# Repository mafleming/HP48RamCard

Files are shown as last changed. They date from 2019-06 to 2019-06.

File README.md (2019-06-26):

HP48RamCard Repository

# A 128K RAM Card for the HP48SX/HP48GX Calculator

This repository contains the schematics and Gerber files needed to create
a 128K RAM card for the HP-48SX/GX calculators. Data sheets for the parts
used are also included. The Bill of Material calls out specific vendor and
vendor part numbers for the passive components used, but any equivalent
part in the SMD 0805 package can be substituted.

The PCB board dimension is 2.125" wide by 3.375" high. The board thickness
is 0.8 mm (1/32") and a 0.8 mm plastic strip must be added so that the card
makes a snug fit in the calculator connector. A PCB thickness of 1.6 mm
can be used instead if a direct fit is desired, but many PCB houses treat
this as a special order size and charge accordingly. If you take this route
be sure to notch both sides of the PCB at the connector end for a distance
of about 1" and depth 0.1" in order to clear the latch engagement pin.

Battery backup is by use of a 12 mm lithium coin cell, either the CR1216 or
the CR1225. The CR1225 has the higher capacity rating of the two at 48 mAh.
Although that's only half the capacity of a CR2016, the Cypress MoBL SRAM
memory device only requires 1 uA in standby mode when the memory is not
selected so battery life should be reasonably long.

## Repository Content

The **Board** directory contains the schematic and PCB board images. Gerber
files are in the Gerber subdirectory. The **Datasheets** directory contains
relevant device information, copyright the manufacturer of course.

## Assembly Notes

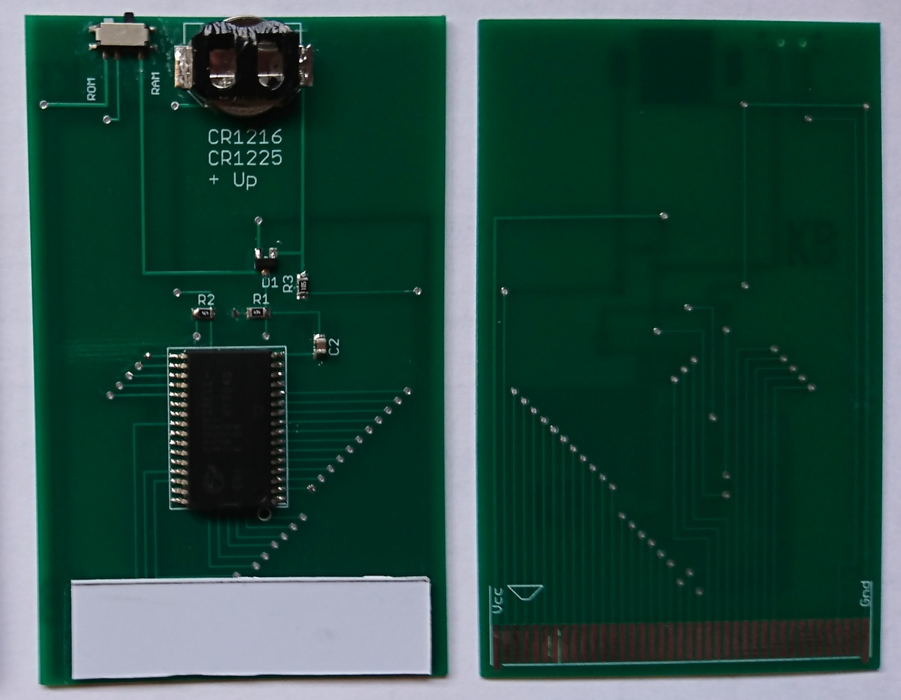
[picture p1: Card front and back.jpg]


The flexible contacts punched from the top of the battery holder are bent
downwards far enough to touch the PCB. Left as-is they will make it more
difficult to insert and remove the battery. The spring force can even be
enough to cause the solder bond between holder tab and PCB to fail
resulting in the battery popping out of the holder. Press the two spring
tabs upwards so that they are closer to the top of the holder.

The battery holder is held by solder to the PCB. Be sure to apply enough to
cover the contacts well because the holder will likely be subject to a
pulling force by those who grasp it to remove the card from the calculator.

The memory protect switch is a more suitable point to grasp the card when
removing it from the calculator. The switch is anchored at its four corners
by solder tabs. In addition, two pegs extend from the bottom of the switch
body into holes in the PCB. Pull upwards in the plane of the PCB.

The top of the battery holder is at the potential of the positive side of
the battery. The holder top presents a possibility of a short, so it is
advised to cover it with a strong adhesive tape or contact sheet. Better
yet, remove the chrome coating from the top with rough sandpaper prior to
soldering the holder to the board, then coat with paint or nail polish
after the soldering operation.

To insure the card contacts are pressed firmly against the card connector
contacts in a calculator, attach a strip of 0.8mm (1/32") thick plastic
behind the contacts on the component side of the PCB. The strip should
meet the lower edge of the PCB and extend upwards about 1/2", but should
not extend the full width of the PCB. Keep the strip about 1/4" from the
left and right sides so that it doesn't cause the card to be blocked by
guide tabs in the card connector block inside the calculator.

## Usage

The card may require a bit of wiggling to clear guide tabs molded into the
card connector assembly. These tabs help guide a commercial card and open
a spring-loaded cover protecting the card contacts. Insertion and removal
is fairly easy in either card slot of an HP48SX. It may help to turn the
calculator on its face and then some downward pressure applied to the back
of the card as the card is pressed down on the top edge.

Insertion in slot 1 of an HP48GX is slightly "stickier" but is easily done
by turning the calculator over. Slot 2 is a different story as the bottom
edge of the PCB catches on a ledge above the connector slot. A plastic
ruler can be use to press the back of the card near the bottom until it
clears the ledge. An alternative is to move the plastic strip from the front
to the back of the PCB just above the row of contacts. The downside is that
the card will now no longer fit in slot 1.

## Project Status

A set of boards were built and tested in HP48SX calculators and outside of
a calculator shell. All cards showed an initial decline in battery cell
voltage before stabilizing around 3 Volts. All cards maintained their
content across the multi-week test period.

The pullup resistor R1 on the Output Enable input to memory was found to be
unnecessary, but did not affect battery life during the test period. I
recommend not installing R1 on any board build.

Improvements to the design include using a smaller contact pad for the battery
bottom since the current size presents a slight risk of a short between the
bottom pad and battery housing if a metal probe is inserted in the general
area. Some designs show a 2.2K current limiting resistor in series with the
CdDet input. A resistor could be added to the design and a zero Ohm short
could be used if the resistor proves to be unnecessary.

The supply voltage to the switch when in the RAM position could be VccOn
from the calculator rather than the memory device supply Vcc. No detrimental
effect has been seen with the arrangement, but if battery life is
compromised as a result, the switch should be moved to the ROM position when
the card is not in use.

## Bill of Material

| Symbol | Device | Part Number | Notes |
| --- | --- | --- | --- |
| IC1 | Cypress 128Kx8 SRAM| CY62128ELL45SXI | SOIC28 |
| D1 | Dual Schottky Diode | ON Semi BAT54CLT1G | SOT23 |
| R2 | 470K, 5% | Panasonic ERJ-P06J474V | 0805 SMD |
| R3 | 1M, 5% | Yageo RC0805JR-071ML | 0805 SMD |
| C1 | 470nF, 16VDC | Taiyo Yuden EMK212B7474MG-T | 0805 SMD |
| U1 | Battery Hldr | Linx BAT-HLD-012-SMT | Use CR1216 or CR1225 |
| U2 | SPDT Switch | Apem MA12R | |

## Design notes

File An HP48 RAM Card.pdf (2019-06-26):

# An HP-48SX/GX 128K RAM Card

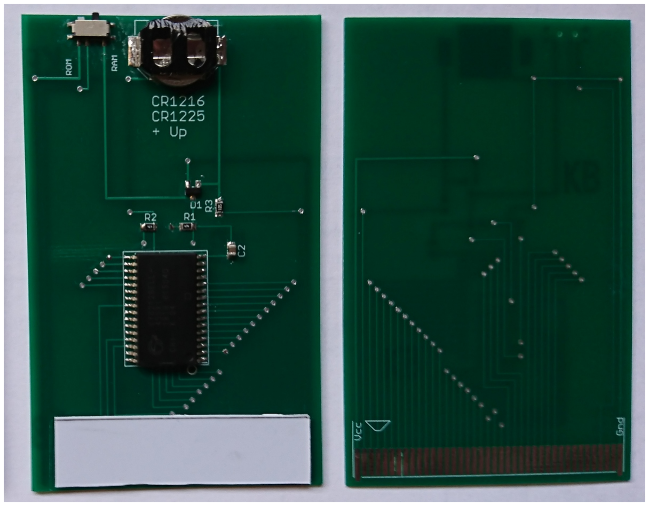
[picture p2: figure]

This repository contains the schematics and Gerber files needed to create a 128K RAM card for the HP-48SX/GX calculators. Data sheets for the parts used are also included. The Bill of Material calls out specific vendor and vendor part numbers for the passive components used, but any equivalent part in the SMD 0805 package can be substituted.
The PCB board dimension is 2.125" wide by 3.375" high. The board thickness is 0.8 mm (1/32") and a 0.8 mm plastic strip must be added so that the card makes a snug fit in the calculator connector. A PCB thickness of 1.6 mm can be used instead if a direct fit is desired, but many PCB houses treat this as a special order size and charge accordingly. If you take this route be sure to notch both sides of the PCB at the connector end for a distance of about 1" and depth 0.1" in order to clear the latch engagement pin.

Battery backup is by use of a 12 mm lithium coin cell, either the CR1216 or the CR1225. The CR1225 has the higher capacity rating of the two at 48 mAh. Although that's only half the capacity of a CR2016, the Cypress MoBL SRAM memory device only requires 1 uA in standby mode when the memory is not selected so battery life should be reasonably long.

### Assembly

Before soldering components thoroughly clean both sides of the PCB with isopropyl alcohol to remove any contaminants that may interfere with the soldering process. Be sure to have on hand plenty of flux to insure good solder wetting and flow.
I generally begin with the small SMD parts. Don’t solder R1 in place as it is not needed. The remaining components R2, R3, C1, and D1 can be held in place with tweezers while soldering. Pick up a bit of solder on your iron tip and bring the tip straight into the end of the component near board level and note the flow of solder under and around the component end. Add plenty of flux beforehand. Spin the board around and solder the other end of the component while applying downward pressure with the tweezers. When all SMD components are soldered you can touch up each solder joint by applying heat and a little more solder from top and sides of the joint.
Solder the memory IC next. The circle mark identifying pin 1 should be downward towards the connector edge of the card. Holding the IC in place, apply plenty of flux and then solder tack the pins at each end of the IC side nearest you. This will hold the IC in place as you solder the pins on the other side of the IC. Turn the card 180, apply flux and then solder each pin on the opposite side. Turn 180 again and solder each pin on the remaining side after applying more flux. If any flux evaporates while you are soldering, stop and apply more to keep your work wet as you go.
Visually inspect each pin for good solder coverage and insure there is no solder bridge between pins. I like to “ring out” the connections afterwards with a multimeter set to the continuity test position. To check for shorts, walk your meter probe pins across successive pairs of via holes surrounding the IC. You can check further by placing one probe on top of an IC pin and the other on its corresponding via. This check doesn’t take long and can save you quite a bit of headscratching if the card fails or acts strangely when you plug it in.
Solder the four corner pads of switch first, holding it in place with tweezers. The switch will align itself to the PCB with two pins on the bottom registering into two holes in the PCB. Be sure to have plenty of solder (and flux) on these corners as the switch will experience a fair amount of force when it is toggled from one position to the other. It is also the place to grab and pull when removing the card from a calculator. Finish with the three switch contact pins themselves and ring out the connections.
The flexible contacts punched from the top of the battery holder are bent downwards far enough to touch the PCB. Left as-is they will make it more difficult to insert and remove the battery. The spring force can even be enough to cause the solder bond between holder tab and PCB to fail resulting in the battery popping out of the holder. Press the two spring tabs upwards so that they are closer to the top of the holder.

The top of the battery holder is at the potential of the positive side of the battery. The holder top presents a possibility of a short, so I would advise covering it with a strong adhesive tape or contact sheet. Better yet, remove the chrome coating from the top with rough sandpaper prior to soldering the holder to the board, then coat with paint or nail polish after the soldering operation.
The battery holder is held by solder to the PCB. Be sure to apply enough to cover the contacts well because the holder will likely be subject to a pulling force by those who grasp it to remove the card from the calculator.
To insure the card contacts are pressed firmly against the card connector contacts in a calculator, attach a strip of 0.8mm (1/32") thick plastic behind the contacts on the component side of the PCB (photo above). The strip should meet the lower edge of the PCB and extend upwards about 1/2", but should not extend the full width of the PCB. Keep the strip about 1/4" from the left and right sides so that it doesn't cause the card to be blocked by guide tabs in the card connector block inside the calculator. Doublesided tape works well to hold the strip.

### Usage

The card may require a bit of wiggling to clear guide tabs molded into the card connector assembly. These tabs help guide a commercial card and open a spring-loaded cover protecting the card contacts. Insertion and removal is fairly easy in either card slot of an HP48SX. It may help to turn the calculator on its face and then apply some downward pressure to the back of the card as the card is pressed down on the top edge.
Insertion in slot 1 of an HP48GX is slightly "stickier" but is easily done by turning the calculator over. Slot 2 is a different story as the bottom edge of the PCB catches on a ledge above the connector slot. A plastic ruler can be use to press the back of the card near the bottom until it clears the ledge. An alternative is to move the plastic strip from the front to the back of the PCB just above the row of contacts. The downside is that now the card will no longer fit in slot 1.
When inserting the card for the first time the calculator will display an Invalid Card Data warning message. For an HP-48GX use the PINIT command to initialize the RAM. Be sure the memory protect switch is in the “RAM” position. For an HP-48SX a card in initialized by storing a variable to the card and then purging it. The calculator will take several seconds to perform the purge as it initializes the card. You can periodically check the voltage of the battery by touching multimeter probes to the top of the battery and a via located below and to the left of the battery holder near the RAM label.

### Bill of Materials

The passive components listed here can readily be substituted from another vendor as long as the value and voltage rating is preserved. The dual diode is also multi-sourced from other vendors. The parts are all available from Mouser as of this date (2019).
Symbol | Device | Part # | Notes
IC1 | Cypress 128Kx8 SRAM | CY62128ELL45SXI | SOIC-28
D1 | Dual Schottky Diode | ON Semi BAT54CLT1G | SOT23
R2 | 470K, 5% Resistor | Panasonic ERJ-P06J474V | SMD 0805
R3 | 1M, 5% Resistor | Yageo RC0805JR-071ML | SMD 0805
C1 | 470nF, 16VDC Capacitor | Taiyo Yuden EMK212B7474MG-T | SMD 0805
U1 | Battery Holder | Linx BAT-HLD-012-SMT | Use CR1216 or CR1225
U2 | SPDT Switch | Apem MA12R

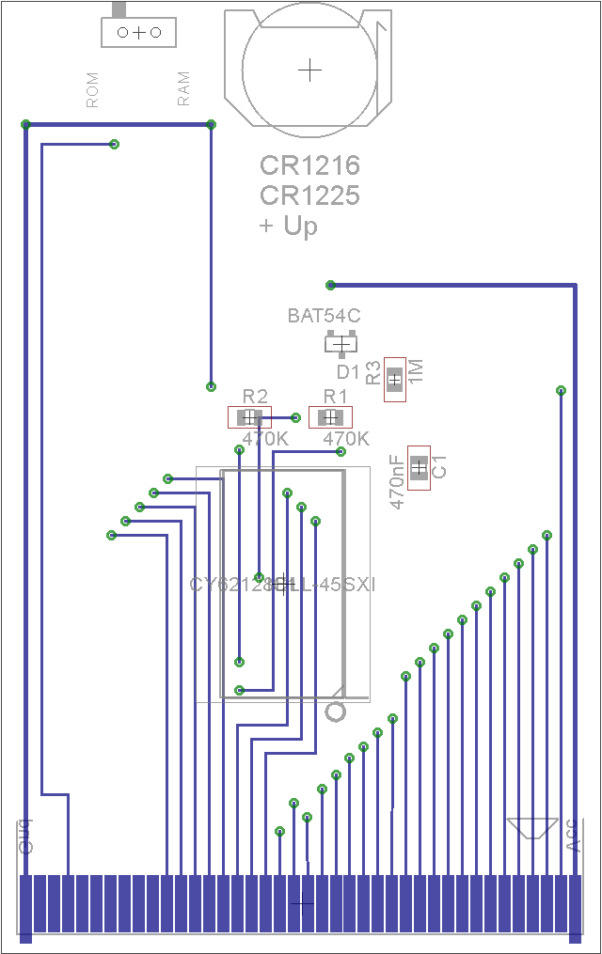
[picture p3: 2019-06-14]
Board/PCB Bottom.png

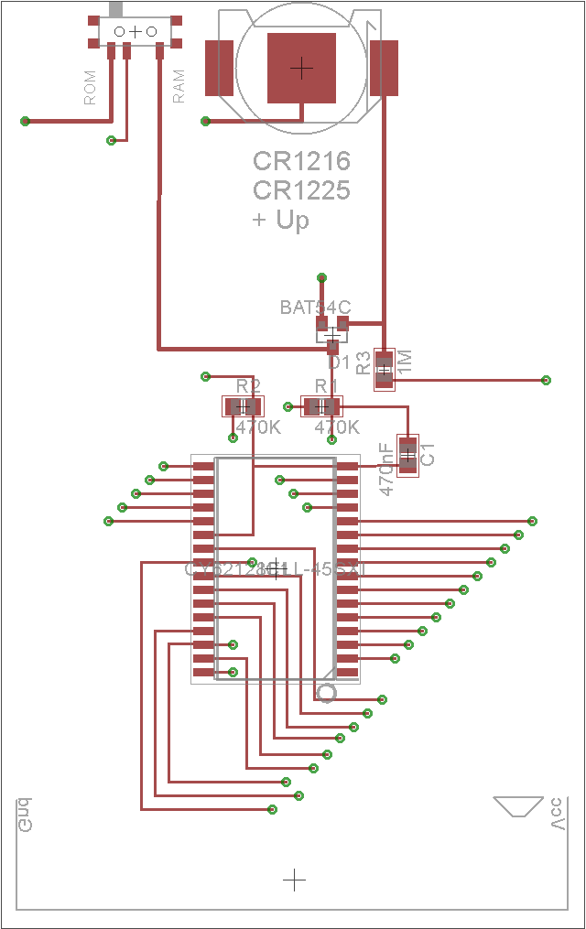
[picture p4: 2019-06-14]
Board/PCB Top.png

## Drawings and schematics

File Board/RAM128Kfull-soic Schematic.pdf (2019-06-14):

A

A

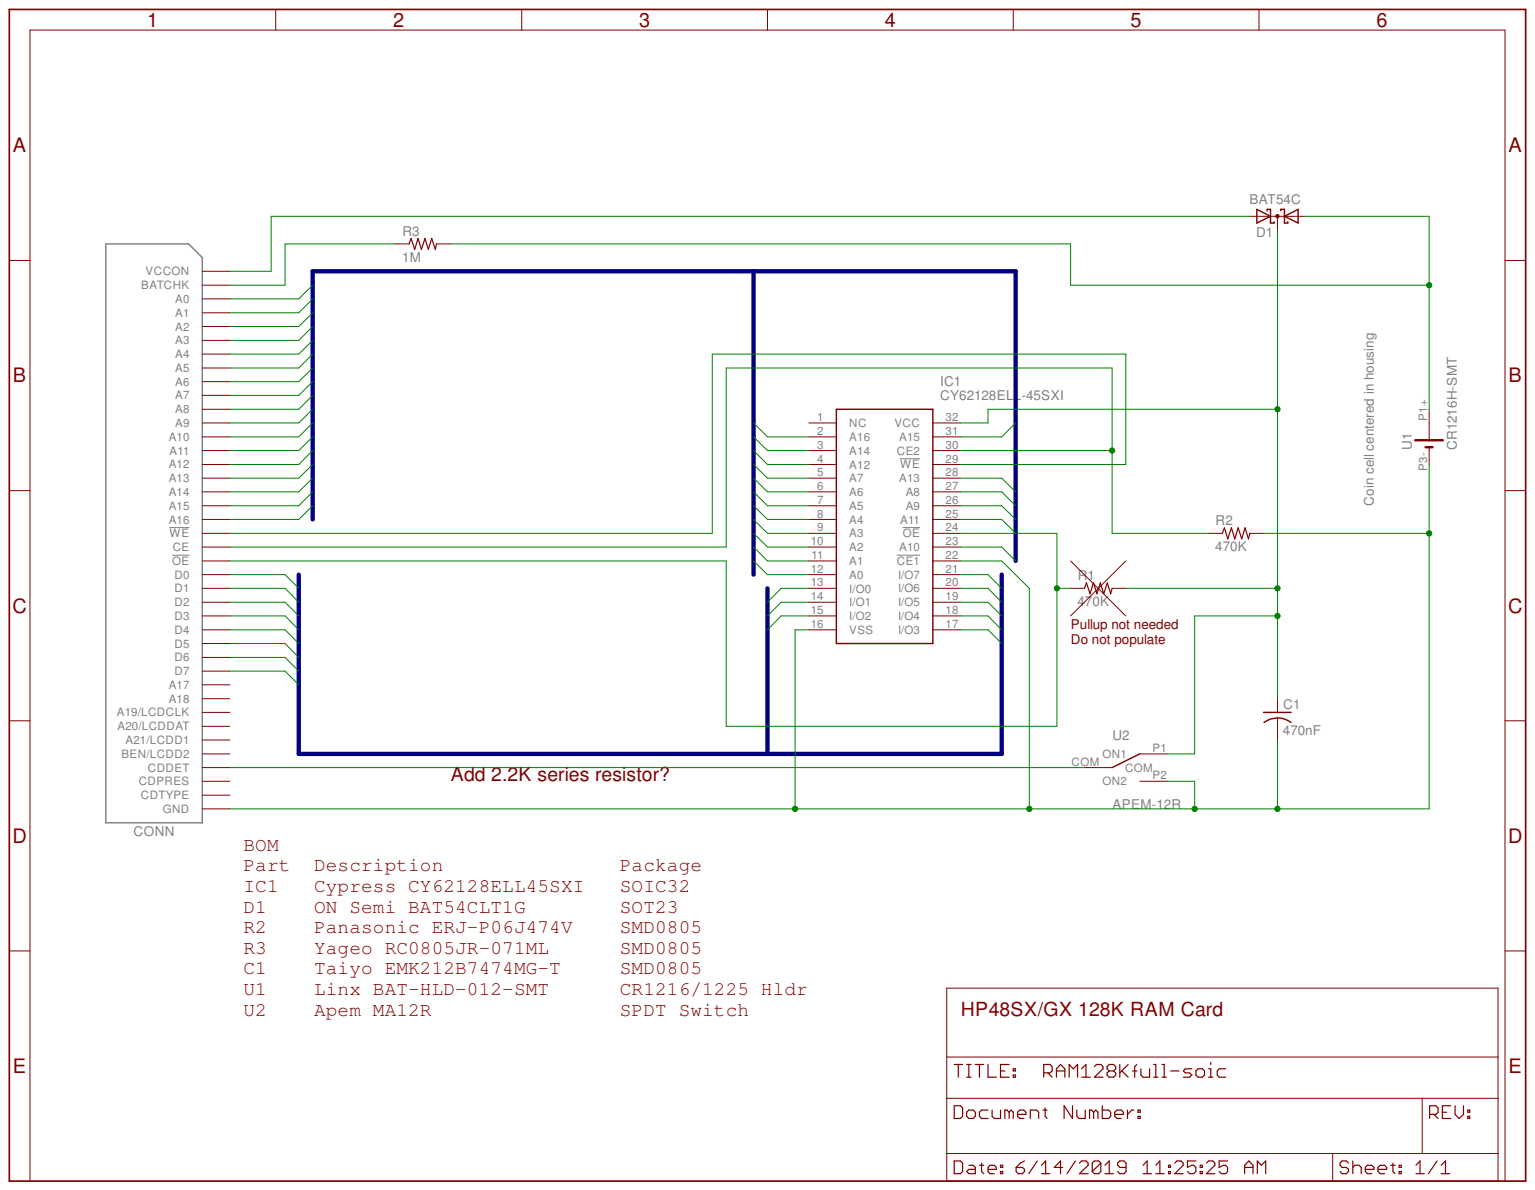
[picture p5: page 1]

Coin cell centered in housing

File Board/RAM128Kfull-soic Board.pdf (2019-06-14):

CR1216
CR1225

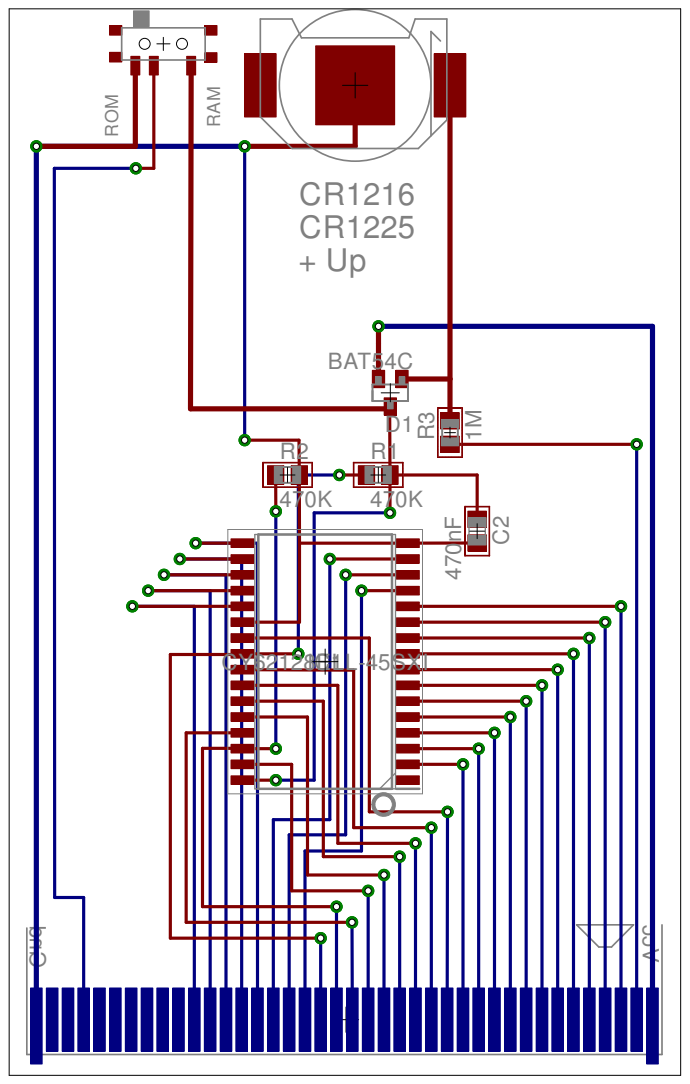
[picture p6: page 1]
Gnd; Vcc; ROM; RAM; BAT54C; CY62128ELL-45SXI

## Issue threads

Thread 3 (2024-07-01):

Make original design files available?

markaudacity, 2024-07-01:
This project has the information to produce a card, but not to improve the design with, EG, a 3D-printed shim with a label and pull tab, a version of the board with additional address switches for use in 32SX slots, etc.

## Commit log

2019-06-14 Revision A Release
    All needed files included. Assembly instructions to follow.
    [RAM128Kfull-soic.GBL, RAM128Kfull-soic.GBO, RAM128Kfull-soic.GBS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]
2019-06-24 Added assembly instructions
    Also have a picture of the board with components.
2019-06-26 Added assembly instructions
    More detailed information than the brief material in the README.md file.
